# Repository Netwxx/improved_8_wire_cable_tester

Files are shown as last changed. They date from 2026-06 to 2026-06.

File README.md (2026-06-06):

# improved_8_wire_cable_tester

Improved 8-wire cable tester with an Arduino Nano (designed for SPI cable, but applicable to more) that tests (with data) forwards and backward, and with a Walsh-Hadamard Parallel Test.

Serial output of arduino is diabled, due to pin D0 being used, connect an I2C LCD display via the designated I2C pins.

Simple wiring diagram included, with KiCad and PDF.

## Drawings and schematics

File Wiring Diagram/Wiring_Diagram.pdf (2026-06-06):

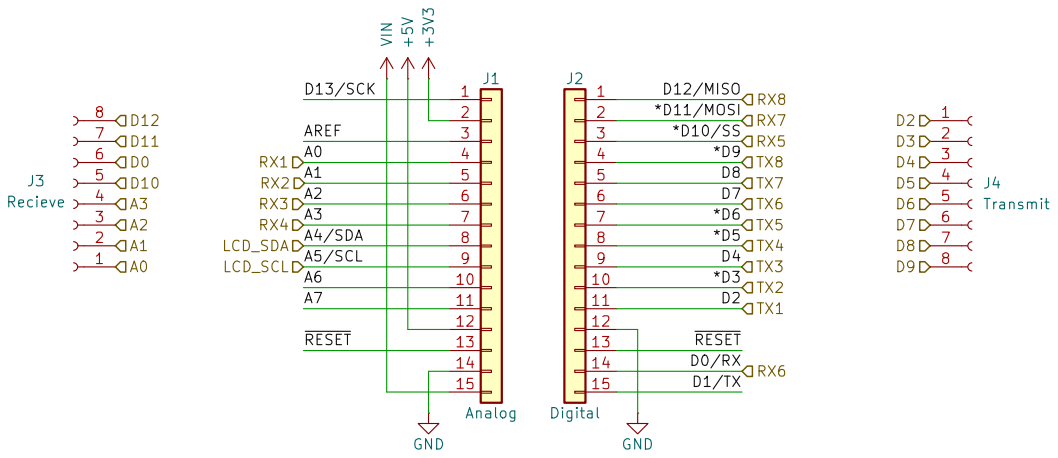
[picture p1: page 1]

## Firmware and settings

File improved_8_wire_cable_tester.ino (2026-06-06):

// ============================================================
//  8-Wire Cable Tester v4.0 — Arduino Nano + I2C 16x2 LCD
//
//  WIRING:
//    No external resistors needed — uses INPUT_PULLUP (active-low)
//    TX pins : D2, D3, D4, D5, D6, D7, D8, D9
//    RX pins : A0, A1, A2, A3, D10, D0, D11, D12
//    LCD SDA : A4
//    LCD SCL : A5
//
//  NOTE: Serial is disabled — D0 is used as RX6.
//        D13 is not used as a test pin (onboard LED causes false reads).
//
//  LCD SEQUENCE PER RUN:
//    Screen 1 : Progress during testing
//    Screen 2 : Summary grid  "1 2 3 4 5 6 7 8 / P P P F P W P P"
//    Screen 3 : Overall result + avg propagation delay
//    Screens 4-19 : Per wire, two screens each —
//      A) Wire N: PASS/WARN/FAIL  +  primary fault or voltage
//      B) Contact resistance (Ω) or error counts + delay + bleed
//    Screen 20: "Retest in 3s..."
//
//  ACTIVE-LOW LOGIC:
//    Drive TX LOW  = send signal
//    Release TX    = INPUT_PULLUP = idle HIGH
//    Open wire     = RX stays HIGH when TX driven LOW
//    Short         = RX goes LOW when a different TX is driven LOW
// ============================================================

#include <Wire.h>
#include <LiquidCrystal_I2C.h>

LiquidCrystal_I2C lcd(0x27, 16, 2);  // change to 0x3F if LCD is blank

// ── Pin assignments ───────────────────────────────────────────
const int TX_PINS[8]       = {2, 3, 4, 5, 6, 7, 8, 9};
const int RX_PINS[8]       = {A0, A1, A2, A3, 10, 0, 11, 12};
const bool RX_HAS_ANALOG[8]= {true, true, true, true, false, false, false, false};
// A0-A3 support analogRead(); D0, D10, D11, D12 do not.

// ── Tuning constants ──────────────────────────────────────────
const int   SETTLE_US        = 500;   // µs after driving — increase for long cables
const int   TEST_REPEAT      = 3;     // PRBS pattern repetitions per phase
const int   PAUSE_MS         = 2500;  // ms each LCD screen is displayed
const int   HISTORY_DEPTH    = 10;    // runs kept for intermittent detection
const int   SHORT_THRESHOLD  = 5;     // shortCount hits needed to flag a short
const int   DECAY_CLEAN_READS= 3;     // consecutive clean reads to decay shortCount
const int   BLEED_WARN_MIN   = 10;    // minimum Walsh bleed count to trigger WARN

const float PULLUP_OHMS      = 50000.0; // Nano internal pull-up ~50kΩ
const float VCC              = 5.0;

// Voltage WARN thresholds
const float WARN_V_HIGH_MIN  = VCC * 0.70; // idle voltage must be above this
const float WARN_V_LOW_MAX   = VCC * 0.30; // active voltage must be below this
const float WARN_R_MAX       = 2000.0;     // contact resistance WARN threshold (Ω)
const float WARN_DELAY_MAX   = 1000.0;     // propagation delay WARN threshold (µs)

// ── PRBS test patterns (active-low: 1 = drive LOW, 0 = release) ──
const uint32_t PRBS_A = 0b10110100110010101111000001101001;
const uint32_t PRBS_B = 0b01001011001101010000111110010110;

// ── Walsh-Hadamard H8 matrix ──────────────────────────────────
const uint8_t WALSH[8] = {
  0b11111111,
  0b11110000,
  0b11001100,
  0b10101010,
  0b11000011,
  0b10100101,
  0b10010110,
  0b10000001
};

// ── Severity levels ───────────────────────────────────────────
enum Severity { SEV_PASS, SEV_WARN, SEV_FAIL };

// ── Per-wire result struct ────────────────────────────────────
struct WireResult {
  Severity severity;
  bool openFault;          // no signal in forward direction
  bool openFaultReverse;   // no signal in reverse only (asymmetric)
  bool idleBleed;          // drive pin reads LOW when it should be idle
  bool shortWith[8];       // confirmed short with each other wire
  bool crossTo;            // signal appeared on a different wire (mis-wire)
  int  crossTarget;        // which wire the signal appeared on
  int  seqBitErrors;       // sequential forward bit errors
  int  seqBitErrorsRev;    // sequential reverse bit errors
  int  parBitErrors;       // Walsh self errors (diagonal)
  int  totalBleed;         // Walsh off-diagonal bleed count
  bool analogValid;        // true if this RX pin supports analogRead
  float avgVoltageActive;  // avg voltage when TX driven LOW (ideal: 0V)
  float avgVoltageIdle;    // avg voltage when TX released HIGH (ideal: 5V)
  float estimatedResistance; // contact+wire resistance in Ω
  float propagationDelayUs;  // signal propagation delay in µs
  bool  intermittent;      // failed some runs but not all
  int   passCount;         // number of passing runs in history
};

WireResult results[8];
int  faultMatrix[8][8];
bool passHistory[8][HISTORY_DEPTH];
int  historyIndex = 0;
int  totalRuns    = 0;

// ── Forward declarations ──────────────────────────────────────
void runSequentialTest(bool reverse);
void runWalshTest();
void analyzeFaultMatrix();
void computeSeverity();
void updateHistory();
void displayResultsLCD();
void clearResults();
void clearFaultMatrix();
void lcdPrint(const char* line1, const char* line2);
inline void drivePin(int pin);
inline void releasePin(int pin);
float measurePropDelay(int txPin, int rxPin);

// ============================================================
//  SETUP
// ============================================================
void setup() {
  lcd.init();
  lcd.backlight();
  lcdPrint("Cable Tester v4", "Initializing...");

  for (int i = 0; i < 8; i++) {
    pinMode(TX_PINS[i], INPUT_PULLUP);
    pinMode(RX_PINS[i], INPUT_PULLUP);
  }

  for (int w = 0; w < 8; w++)
    for (int r = 0; r < HISTORY_DEPTH; r++)
      passHistory[w][r] = false;

  delay(1000);
}

// ============================================================
//  MAIN LOOP
// ============================================================
void loop() {
  lcdPrint("Cable Tester v4", "Testing...");
  delay(400);

  clearResults();
  clearFaultMatrix();

  lcdPrint("Phase 1a/3", "Seq. forward...");
  runSequentialTest(false);

  lcdPrint("Phase 1b/3", "Seq. reverse...");
  runSequentialTest(true);

  lcdPrint("Phase 2/3", "Walsh parallel..");
  runWalshTest();

  analyzeFaultMatrix();
  computeSeverity();
  updateHistory();
  displayResultsLCD();
}

// ============================================================
//  DRIVE / RELEASE helpers
//  drivePin  — sets OUTPUT LOW  (sends signal, active-low)
//  releasePin — sets INPUT_PULLUP (idle, floats HIGH via 50kΩ)
//  Never drive HIGH as OUTPUT — two outputs fighting causes damage.
// ============================================================
inline void drivePin(int pin) {
  pinMode(pin, OUTPUT);
  digitalWrite(pin, LOW);
}

inline void releasePin(int pin) {
  pinMode(pin, INPUT_PULLUP);
}

// ============================================================
//  PROPAGATION DELAY MEASUREMENT
//  Drives txPin LOW, polls rxPin until it follows.
//  Returns elapsed µs, or -1.0 if no response within 5ms.
// ============================================================
float measurePropDelay(int txPin, int rxPin) {
  releasePin(txPin);
  delayMicroseconds(400);

  unsigned long t0       = micros();
  unsigned long deadline = t0 + 5000UL;
  drivePin(txPin);

  while (micros() < deadline) {
    if (digitalRead(rxPin) == LOW) {
      float d = (float)(micros() - t0);
      releasePin(txPin);
      delayMicroseconds(SETTLE_US * 2);
      return d;
    }
  }
  releasePin(txPin);
  delayMicroseconds(SETTLE_US * 2);
  return -1.0;
}

// ============================================================
//  PHASE 1 — SEQUENTIAL SINGLE-WIRE TEST
//
//  Tests one wire at a time, in both directions.
//  Sends PRBS_A and PRBS_B patterns, checks the expected RX pin
//  and watches idle pins for unexpected LOWs (shorts).
//
//  Short detection uses a hysteresis counter per idle pin:
//  shortCount increments on each unexpected LOW, but requires
//  DECAY_CLEAN_READS consecutive clean reads to decrement by 1.
//  A short is only committed if shortCount >= SHORT_THRESHOLD.
// ============================================================
void runSequentialTest(bool reverse) {
  const int* drivePins = reverse ? RX_PINS : TX_PINS;
  const int* readPins  = reverse ? TX_PINS : RX_PINS;

  for (int i = 0; i < 8; i++) {
    releasePin(drivePins[i]);
    releasePin(readPins[i]);
  }
  delayMicroseconds(SETTLE_US * 4);

  for (int w = 0; w < 8; w++) {

    // Progress bar on LCD
    lcd.clear();
    lcd.setCursor(0, 0);
    lcd.print(reverse ? "Rev wire " : "Fwd wire ");
    lcd.print(w + 1);
    lcd.setCursor(0, 1);
    lcd.print("[");
    for (int b = 0; b < w * 2; b++) lcd.print("=");
    lcd.print(">");

    int  bitErrors     = 0;
    long analogSumAct  = 0;
    long analogSumIdle = 0;
    int  analogCntAct  = 0;
    int  analogCntIdle = 0;
    bool localOpen     = false;
    bool localIdle     = false;
    int  shortCount[8] = {};
    int  cleanCount[8] = {};

    // Measure propagation delay on forward pass only
    float propDelay = -1.0;
    if (!reverse)
      propDelay = measurePropDelay(drivePins[w], readPins[w]);

    for (int rep = 0; rep < TEST_REPEAT; rep++) {
      for (int pass = 0; pass < 2; pass++) {
        uint32_t pattern = (pass == 0) ? PRBS_A : PRBS_B;

        for (int bit = 31; bit >= 0; bit--) {
          bool sendLow = (pattern >> bit) & 1;

          if (sendLow) drivePin(drivePins[w]);
          else         releasePin(drivePins[w]);
          delayMicroseconds(SETTLE_US);

          // Read all RX pins at once
          bool rxState[8];
          for (int r = 0; r < 8; r++)
            rxState[r] = (digitalRead(readPins[r]) == LOW);

          // Check expected pin
          if (rxState[w] != sendLow) {
            bitErrors++;
            if (sendLow && !rxState[w]) localOpen = true;
          }

          // Analog sampling on forward pass for analog-capable pins
          if (!reverse && RX_HAS_ANALOG[w]) {
            if (sendLow) { analogSumAct  += analogRead(readPins[w]); analogCntAct++;  }
            else         { analogSumIdle += analogRead(readPins[w]); analogCntIdle++; }
          }

          // Idle pin monitoring
          for (int r = 0; r < 8; r++) {
            if (r == w) continue;

            // Idle drive pin should never read LOW
            if (digitalRead(drivePins[r]) == LOW) localIdle = true;

            // Unexpected LOW on idle RX while we are driving LOW = possible short
            if (sendLow && rxState[r]) {
              shortCount[r]++;
              cleanCount[r] = 0;
            } else {
              cleanCount[r]++;
              if (cleanCount[r] >= DECAY_CLEAN_READS) {
                if (shortCount[r] > 0) shortCount[r]--;
                cleanCount[r] = 0;
              }
            }
          }

        } // bit
      } // pass
    } // repeat

    releasePin(drivePins[w]);
    delayMicroseconds(SETTLE_US * 2);

    // Commit shorts (forward pass only — Walsh confirms later)
    if (!reverse) {
      for (int r = 0; r < 8; r++)
        if (shortCount[r] >= SHORT_THRESHOLD)
          results[w].shortWith[r] = true;
    }

    // Store forward results
    if (!reverse) {
      results[w].seqBitErrors       = bitErrors;
      results[w].openFault          = localOpen;
      results[w].idleBleed          = localIdle;
      results[w].propagationDelayUs = propDelay;
      results[w].analogValid        = RX_HAS_ANALOG[w];

      if (RX_HAS_ANALOG[w] && analogCntAct > 0 && analogCntIdle > 0) {
        results[w].avgVoltageActive = (analogSumAct  / (float)analogCntAct)  * (VCC / 1023.0);
        results[w].avgVoltageIdle   = (analogSumIdle / (float)analogCntIdle) * (VCC / 1023.0);
        // Contact resistance: R = R_pullup * V_active / (Vcc - V_active)
        float va = results[w].avgVoltageActive;
        results[w].estimatedResistance = (va < (VCC - 0.1))
          ? PULLUP_OHMS * va / (VCC - va)
          : -1.0;
      } else {
        results[w].avgVoltageActive    = -1.0;
        results[w].avgVoltageIdle      = -1.0;
        results[w].estimatedResistance = -1.0;
      }

    // Store reverse results
    } else {
      results[w].seqBitErrorsRev  = bitErrors;
      // Asymmetric open: forward clean but reverse fails = diode or one-way contact
      results[w].openFaultReverse = (!results[w].openFault && bitErrors > 0);
    }
  }

  for (int i = 0; i < 8; i++) {
    releasePin(TX_PINS[i]);
    releasePin(RX_PINS[i]);
  }
  delayMicroseconds(SETTLE_US * 4);
}

// ============================================================
//  PHASE 2 — WALSH-HADAMARD PARALLEL TEST
//
//  Drives multiple TX pins simultaneously using the H8 Walsh
//  matrix so every possible combination of wires is exercised.
//  Each phase uses a different Walsh row as the drive pattern.
//
//  Fault matrix logic:
//    Diagonal   (tx==rx): self-error if RX doesn't follow its TX
//    Off-diagonal       : bleed if RX is LOW but its own TX is NOT active
//    Idle-idle          : NOT a fault (both floating HIGH is correct)
// ============================================================
void runWalshTest() {
  uint32_t patterns[2] = {PRBS_A, PRBS_B};

  for (int i = 0; i < 8; i++) releasePin(TX_PINS[i]);
  delayMicroseconds(SETTLE_US * 4);

  for (int phase = 0; phase < 8; phase++) {

    // Progress bar on LCD
    lcd.clear();
    lcd.setCursor(0, 0);
    lcd.print("Walsh ");
    lcd.print(phase + 1);
    lcd.print("/8 x");
    lcd.print(TEST_REPEAT);
    lcd.setCursor(0, 1);
    lcd.print("[");
    for (int b = 0; b < phase * 2; b++) lcd.print("=");
    lcd.print(">");

    for (int rep = 0; rep < TEST_REPEAT; rep++) {
      for (int p = 0; p < 2; p++) {
        for (int bit = 31; bit >= 0; bit--) {
          bool bitActive = (patterns[p] >> bit) & 1;

          bool txActive[8];
          for (int tx = 0; tx < 8; tx++) {
            txActive[tx] = bitActive && ((WALSH[tx] >> (7 - phase)) & 1);
            if (txActive[tx]) drivePin(TX_PINS[tx]);
            else              releasePin(TX_PINS[tx]);
          }
          delayMicroseconds(SETTLE_US);

          bool rxState[8];
          for (int rx = 0; rx < 8; rx++)
            rxState[rx] = (digitalRead(RX_PINS[rx]) == LOW);

          for (int rx = 0; rx < 8; rx++) {
            // Diagonal: self-error if RX doesn't match its TX state
            if (rxState[rx] != txActive[rx])
              faultMatrix[rx][rx]++;

            // Off-diagonal: RX LOW when its own TX is NOT active = bleed
            if (rxState[rx] && !txActive[rx]) {
              for (int tx = 0; tx < 8; tx++) {
                if (tx != rx && txActive[tx])
                  faultMatrix[tx][rx]++;
              }
            }
          }

        } // bit
      } // prbs pass
    } // repeat

    for (int tx = 0; tx < 8; tx++) releasePin(TX_PINS[tx]);
    delayMicroseconds(SETTLE_US * 2);
  }

  for (int i = 0; i < 8; i++) releasePin(TX_PINS[i]);
}

// ============================================================
//  ANALYZE FAULT MATRIX
//
//  Snapshots sequential shorts, clears them, then re-confirms
//  only those backed by Walsh evidence too. This prevents
//  capacitive coupling (which only appears in Walsh) from being
//  promoted to a hard short, and prevents sequential noise from
//  surviving without Walsh confirmation.
//
//  A hard SHORT requires all three:
//    1. Sequential phase saw it bidirectionally
//    2. Walsh bleed is bidirectional
//    3. Walsh bleed count > 10% of total bits
// ============================================================
void analyzeFaultMatrix() {
  int totalBits = 8 * 2 * 32 * TEST_REPEAT;

  // Snapshot then clear sequential shorts
  bool seqShorts[8][8];
  for (int w = 0; w < 8; w++)
    for (int r = 0; r < 8; r++) {
      seqShorts[w][r]         = results[w].shortWith[r];
      results[w].shortWith[r] = false;
    }

  for (int w = 0; w < 8; w++) {
    results[w].parBitErrors = faultMatrix[w][w];
    results[w].totalBleed   = 0;

    for (int r = 0; r < 8; r++) {
      if (r == w) continue;
      if (faultMatrix[w][r] == 0) continue;

      results[w].totalBleed += faultMatrix[w][r];

      // Cross-wire: self is open + another wire has strong signal = mis-wired
      if (results[w].openFault && faultMatrix[w][r] > (totalBits / 4)) {
        results[w].crossTo     = true;
        results[w].crossTarget = r;
        continue;
      }

      // Confirm hard short
      bool seqBidi   = seqShorts[w][r] && seqShorts[r][w];
      bool walshBidi = faultMatrix[r][w] > 0;
      bool walshHeavy= faultMatrix[w][r] > (totalBits / 10);
      if (seqBidi && walshBidi && walshHeavy)
        results[w].shortWith[r] = true;
      // else: bleed only, totalBleed already incremented → may trigger WARN
    }
  }
}

// ============================================================
//  COMPUTE SEVERITY
// ============================================================
void computeSeverity() {
  int seqTotalBits = 2 * 32 * TEST_REPEAT;

  for (int w = 0; w < 8; w++) {
    bool anyShort = false;
    for (int r = 0; r < 8; r++)
      if (results[w].shortWith[r]) anyShort = true;

    bool hardFail =
      results[w].openFault                          ||
      results[w].crossTo                            ||
      anyShort                                      ||
      results[w].seqBitErrors  > (seqTotalBits / 4)||
      results[w].parBitErrors  > 0;

    bool warnFlag =
      results[w].openFaultReverse                   ||
      results[w].intermittent                       ||
      results[w].idleBleed                          ||
      results[w].seqBitErrors    > 0                ||
      results[w].seqBitErrorsRev > 0                ||
      results[w].totalBleed      > BLEED_WARN_MIN   ||
      (results[w].analogValid && results[w].avgVoltageIdle   >= 0 &&
       results[w].avgVoltageIdle   < WARN_V_HIGH_MIN)            ||
      (results[w].analogValid && results[w].avgVoltageActive >= 0 &&
       results[w].avgVoltageActive > WARN_V_LOW_MAX)             ||
      (results[w].analogValid &&
       results[w].estimatedResistance > WARN_R_MAX)              ||
      (results[w].propagationDelayUs  > 0 &&
       results[w].propagationDelayUs  > WARN_DELAY_MAX);

    if      (hardFail) results[w].severity = SEV_FAIL;
    else if (warnFlag) results[w].severity = SEV_WARN;
    else               results[w].severity = SEV_PASS;
  }
}

// ============================================================
//  PASS HISTORY & INTERMITTENT DETECTION
// ============================================================
void updateHistory() {
  totalRuns = min(totalRuns + 1, HISTORY_DEPTH);
  for (int w = 0; w < 8; w++) {
    passHistory[w][historyIndex] = (results[w].severity == SEV_PASS);
    int passes = 0;
    int runs   = min(totalRuns, HISTORY_DEPTH);
    for (int r = 0; r < runs; r++)
      passes += passHistory[w][r] ? 1 : 0;
    results[w].passCount    = passes;
    results[w].intermittent = (passes > 0 && passes < runs);
  }
  historyIndex = (historyIndex + 1) % HISTORY_DEPTH;
}
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

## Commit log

2026-06-06 First version improved 8 wire cable tester.
2026-06-06 Trying to push a lot of stuff into it, currently not working.
    [improved_8_wire_cable_tester.ino]
2026-06-06 Currently not working, but a version none-the-less.
    [improved_8_wire_cable_tester.ino]
2026-06-06 Fucked up with some commit stuff, and others, but fixed now (I think).
    [improved_8_wire_cable_tester.ino]
2026-06-06 Working well, created wiring diagram.
    [Schematic.kicad_sch]
